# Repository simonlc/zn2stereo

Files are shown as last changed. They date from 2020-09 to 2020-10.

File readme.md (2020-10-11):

# Capcom ZN-2 stereo breakout board

The ZN-2 stereo breakout board is a custom PCB that connects to a ZN-2 audio header and provide line level stereo output. The attenuation circuit is based on the Sanwa VC-J [documented here](http://www.neo-geo.com/forums/showthread.php?172861-A-different-attenuation-circuit).

It's mounted by a single standoff, and is supported by the connector that sits on the stereo header.

- Online BOM: https://octopart.com/bom-tool/YipwlKb2
- Purchase bare PCB online: https://oshpark.com/shared_projects/Dj41HkF0

### Donate: https://paypal.me/zn2stereo

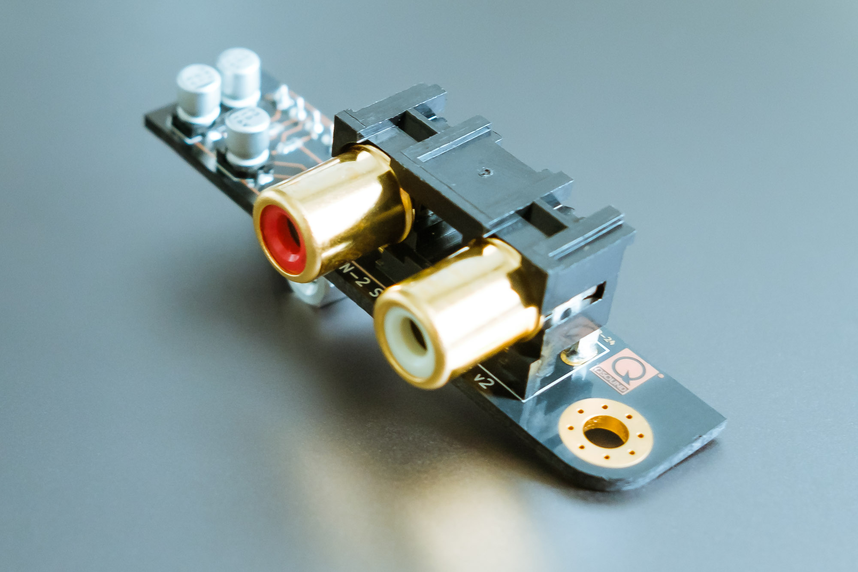
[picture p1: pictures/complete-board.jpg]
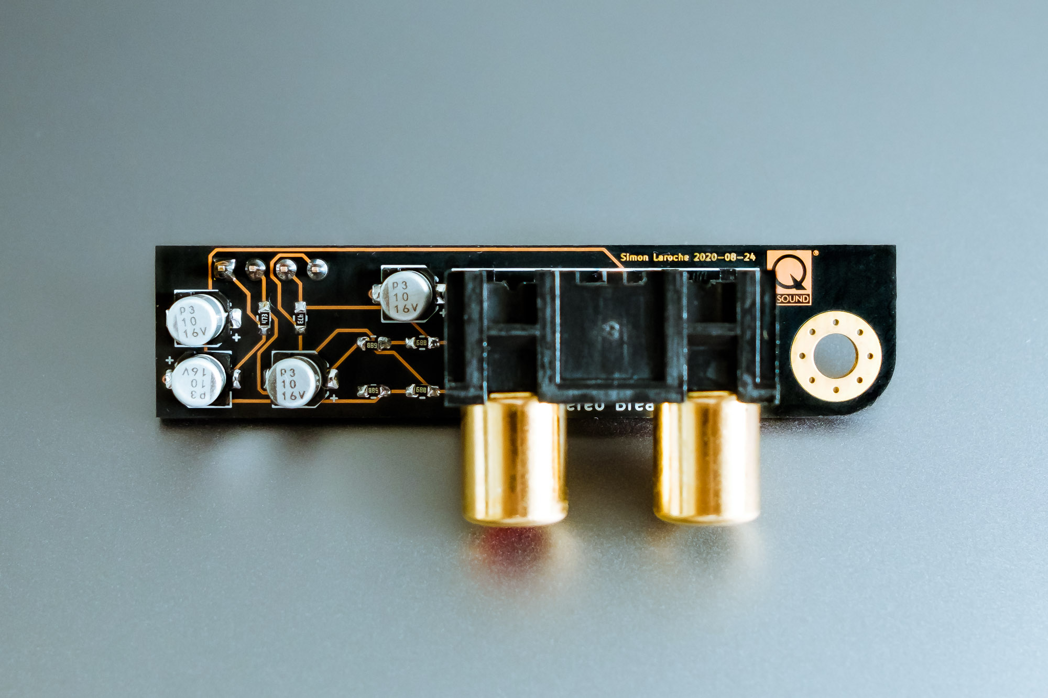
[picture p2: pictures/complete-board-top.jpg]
 

## Assembly

To assemble the board, soldering experience is needed. Parts in the BOM must be acquired, and a custom PCB printed. The PCB can be printed from anywhere, but a link is provided to purchase from OSH Park for convenience. If you have any questions regarding the installation or purchase please create an issue.

## Installation

For ZN-2 games, the stereo/mono switch next to the volume pot must be set to stereo. The game also needs to be set to stereo in the test menu.

The BOM includes M3 standoff and screws. Depending on your PCB standoffs, these might not be the right size, please double check!

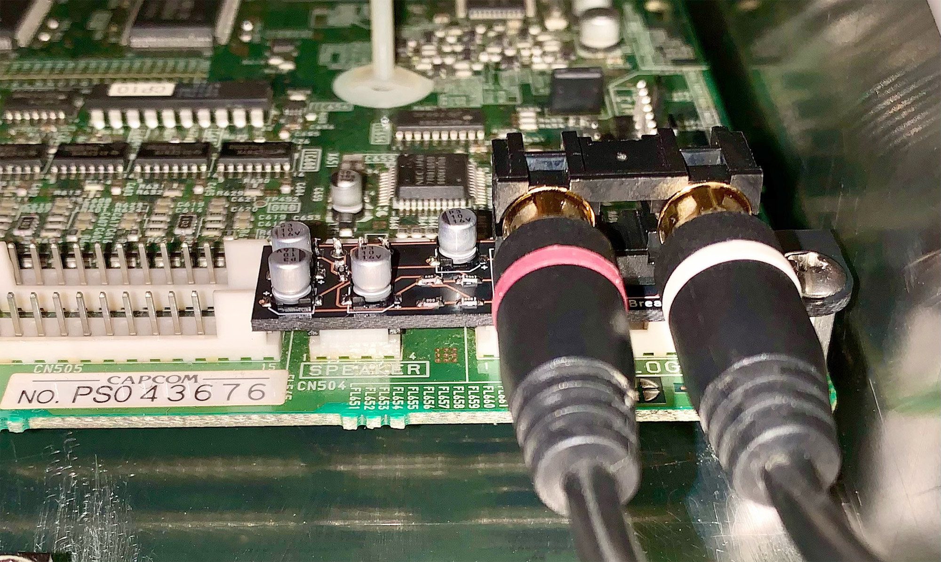
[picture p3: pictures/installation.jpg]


## Compatibility

This board may be compatible with other ZN-2 style hardware.

| Hardware | Compatibility |
| --- | --- |
| Capcom ZN-2 | ✅  Working |
| Capcom ZN-1 | ✅  Working |
| Taito G-Net | ❓  Not tested |
| Tecmo TPS | ❓  Not tested |
| Taito FX-1A System | ❓  Not tested |
| Taito FX-1B System | ❓  Not tested |

## License
Licensed under the TAPR Open Hardware License (www.tapr.org/OHL)

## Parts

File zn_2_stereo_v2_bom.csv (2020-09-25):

Qty | Line Item | Manufacturer | MPN | Octopart URL | Schematic Reference | Internal Part Number | Description | Total Qty (@ Batch Size: 3) | SKU | SKU | SKU | SKU | Packaging | Packaging | Packaging | Packaging | Unit Price (@ Batch Size: 3) | Unit Price (@ Batch Size: 3) | Unit Price (@ Batch Size: 3) | Unit Price (@ Batch Size: 3) | In Stock | In Stock | In Stock | In Stock | MOQ | MOQ | MOQ | MOQ | URL | URL | URL | URL | Distributor [Lowest Price (Overall)] | SKU [Lowest Price (Overall)] | Packaging [Lowest Price (Overall)] | Unit Price (@ Batch Size: 3) [Lowest Price (Overall)] | Line Total [Lowest Price (Overall)] | Batch Total [Lowest Price (Overall)] | In Stock [Lowest Price (Overall)] | MOQ [Lowest Price (Overall)] | URL [Lowest Price (Overall)] | Notes
 |  |  |  |  |  |  |  |  | Digi-Key | Future Electronics | Mouser | RS Components | Digi-Key | Future Electronics | Mouser | RS Components | Digi-Key | Future Electronics | Mouser | RS Components | Digi-Key | Future Electronics | Mouser | RS Components | Digi-Key | Future Electronics | Mouser | RS Components | Digi-Key | Future Electronics | Mouser | RS Components
1 | PJRAN2X1U01AUX | Switchcraft | PJRAN2X1U01AUX | https://octopart.com/pjran2x1u01aux-switchcraft-7628639 |  |  | Stereo RCA jacks | 3 | SC2534-ND |  | 502-PJRAN2X1U01AUX |  | Bulk |  |  |  | 3.2303490999999998 |  | 2.9500295499999996 |  | 290 |  | 2021 |  | 1 |  | 1 |  | https://octopart.com/click/track?ai=8237&sig=036b407&sid=459&ppid=7628639&vpid=410285749&ct=offers |  | https://octopart.com/click/track?ai=8237&sig=053ed9f&sid=2401&ppid=7628639&vpid=84769496&ct=offers |  | Newark | 09N0908 |  | 2.23 | 2.23 | 6.6899999999999995 | 23 | 1 | https://octopart.com/click/track?ai=8237&sig=038ab07&sid=2402&ppid=7628639&vpid=496454911&ct=offers
4 | CR0603-FX-4991ELF | Bourns | CR0603-FX-4991ELF | https://octopart.com/cr0603-fx-4991elf-bourns-2326660 |  |  | 5K resistor | 12 | CR0603-FX-4991ELFCT-ND |  | 652-CR0603FX-4991ELF |  | Cut Tape |  | Tape & Reel |  | 0.020022824999999998 |  | 0.026697099999999998 |  | 87845 |  | 50585 |  | 1 |  | 1 |  | https://octopart.com/click/track?ai=8237&sig=0655f03&sid=459&ppid=2326660&vpid=61158165&ct=offers |  | https://octopart.com/click/track?ai=8237&sig=034b805&sid=2401&ppid=2326660&vpid=37729650&ct=offers |  | Arrow Electronics | CR0603-FX-4991ELF | Cut Tape | 0.013348549999999999 | 0.053394199999999996 | 0.16018259999999998 | 19804 | 1 | https://octopart.com/click/track?ai=8237&sig=035ebea&sid=1106&ppid=2326660&vpid=473159437&ct=offers
4 | UWX1C100MCL1GB | Nichicon | UWX1C100MCL1GB | https://octopart.com/uwx1c100mcl1gb-nichicon-203107 |  |  | Capacitor | 12 | 493-2100-1-ND | 7940968 | 647-UWX1C100MCL1 | 7395548 | Cut Tape | Cut Tape | Tape & Reel |  | 0.21357679999999998 | 0.353736575 | 0.353736575 | 0.19411069810396556 | 179 | 3011 | 25372 | 480 | 1 | 1 | 1 | 10 | https://octopart.com/click/track?ai=8237&sig=0481c12&sid=459&ppid=203107&vpid=1196165&ct=offers | https://octopart.com/click/track?ai=8237&sig=0ecec06&sid=2454&ppid=203107&vpid=19666315&ct=offers | https://octopart.com/click/track?ai=8237&sig=0613dbd&sid=2401&ppid=203107&vpid=39505068&ct=offers | https://octopart.com/click/track?ai=8237&sig=0d7caaa&sid=10022&ppid=203107&vpid=199081830&ct=offers | LCSC | C445047 |  | 0.0642 | 0.2568 | 0.7704 | 1900 | 10 | https://octopart.com/click/track?ai=8237&sig=0725ec1&sid=27971&ppid=203107&vpid=609063197&ct=offers
2 | CRCW060347K0JNEAC | Vishay | CRCW060347K0JNEAC | https://octopart.com/crcw060347k0jneac-vishay-23798439 |  |  | 47K resistor | 6 | 541-4061-1-ND |  | 71-CRCW060347K0JNEAC |  | Cut Tape |  | Tape & Reel |  | 0.1334855 |  | 0.1334855 |  | 98410 |  | 28688 |  | 1 |  | 1 |  | https://octopart.com/click/track?ai=8237&sig=00cb439&sid=459&ppid=23798439&vpid=454353578&ct=offers |  | https://octopart.com/click/track?ai=8237&sig=05cf147&sid=2401&ppid=23798439&vpid=458953569&ct=offers |  | Arrow.cn | CRCW060347K0JNEAC#VISHAY |  | 0.08593176710061944 | 0.17186353420123887 | 0.5155906026037166 | 7530 | 1 | https://octopart.com/click/track?ai=8237&sig=0a4e952&sid=28928&ppid=23798439&vpid=617453892&ct=offers
1 | PPPC041LFBN-RC | Sullins | PPPC041LFBN-RC | https://octopart.com/pppc041lfbn-rc-sullins-271053 |  |  | 4 pin connector | 3 | S7037-ND | 6009019 |  |  | Tray | Tray |  |  | 0.6273818499999999 | 0.3804336749999999 |  |  | 30804 | 5313 |  |  | 1 | 1 |  |  | https://octopart.com/click/track?c=1&ai=8237&sig=038629e&sid=459&ppid=271053&vpid=1385044&ct=offers | https://octopart.com/click/track?ai=8237&sig=075b0fd&sid=2454&ppid=271053&vpid=110050916&ct=offers |  |  | Future Electronics | 6009019 | Tray | 0.3804336749999999 | 0.3804336749999999 | 1.1413010249999997 | 5313 | 1 | https://octopart.com/click/track?ai=8237&sig=075b0fd&sid=2454&ppid=271053&vpid=110050916&ct=offers
1 | 24337 | Keystone | 24337 | https://octopart.com/24337-keystone-7139829 |  |  | 1 cm M3 Standoff | 3 | 36-24337-ND | 1054718 | 534-24337 |  | Bulk | Bulk | Bulk |  | 0.6273818499999999 |  | 0.60068475 |  | 5739 | 8 | 3426 |  | 1 | 100 | 1 |  | https://octopart.com/click/track?ai=8237&sig=064ec3c&sid=459&ppid=7139829&vpid=212424319&ct=offers | https://octopart.com/click/track?ai=8237&sig=05daba1&sid=2454&ppid=7139829&vpid=416853497&ct=offers | https://octopart.com/click/track?ai=8237&sig=04f8fe6&sid=2401&ppid=7139829&vpid=37671153&ct=offers |  | Carlton-Bates | 78382495417 |  | 0.5472905499999999 | 0.5472905499999999 | 1.6418716499999997 | 0 | 1 | https://octopart.com/click/track?c=1&ai=8237&sig=027bb87&sid=18369&ppid=7139829&vpid=521657115&ct=offers
1 | MPMS 003 0005 PH | Building Fasteners | MPMS 003 0005 PH | https://octopart.com/mpms+003+0005+ph-building+fasteners-374100 |  |  | M3 screw | 3 | H742-ND |  |  |  | Bulk |  |  |  |  |  |  |  | 40100 |  |  |  | 100 |  |  |  | https://octopart.com/click/track?c=1&ai=8237&sig=0800b8d&sid=459&ppid=374100&vpid=1717444&ct=offers |  |  |  | Digi-Key | H742-ND | Bulk |  |  |  | 40100 | 100 | https://octopart.com/click/track?c=1&ai=8237&sig=0800b8d&sid=459&ppid=374100&vpid=1717444&ct=offers

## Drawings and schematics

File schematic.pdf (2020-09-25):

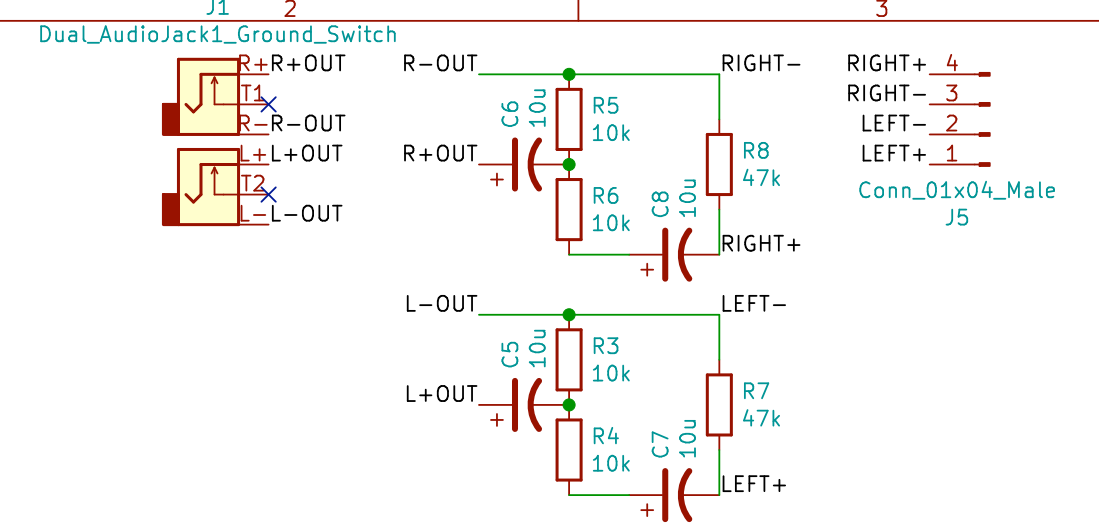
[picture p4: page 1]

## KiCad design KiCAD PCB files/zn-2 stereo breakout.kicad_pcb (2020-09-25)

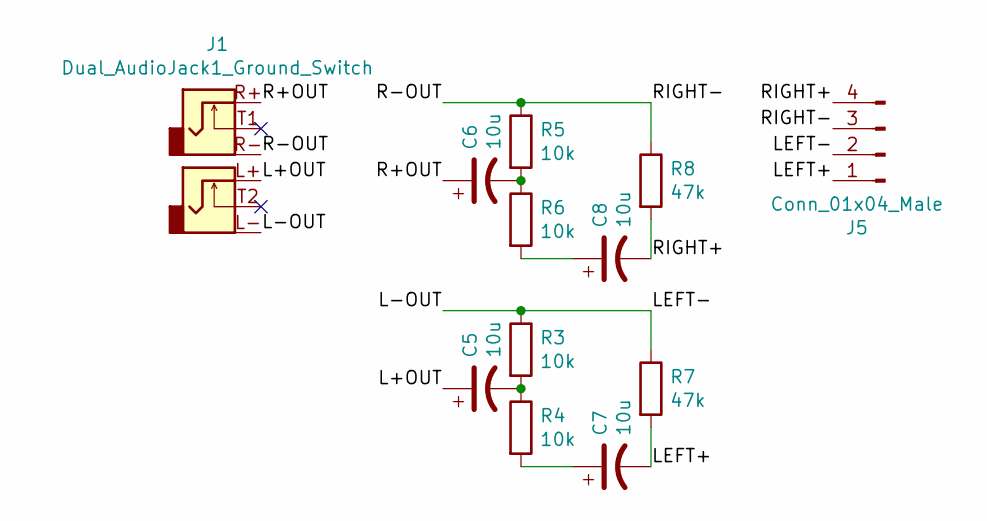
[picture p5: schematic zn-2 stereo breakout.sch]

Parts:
C5, C6, C7, C8: 10u; CP_Elec_4x5.8
J1: Dual_AudioJack1_Ground_Switch; Switchcraft PJRAN2X1U01AUX
J5: Conn_01x04_Male; PinSocket_1x04_P2.54mm_Vertical
R3, R4, R5, R6: 10k; R_0603_1608Metric_Pad1.05x0.95mm_HandSolder
R7, R8: 47k; R_0603_1608Metric_Pad1.05x0.95mm_HandSolder

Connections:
/L+OUT: C5.1, J1.L+
/L-OUT: J1.L-, J5.2, R3.1, R7.1
/LEFT+: C7.2, J5.1, R7.2
/R+OUT: C6.1, J1.R+
/R-OUT: J1.R-, J5.3, R5.1, R8.1
/RIGHT+: C8.2, J5.4, R8.2
unnamed: C5.2, R3.2, R4.1
unnamed: C6.2, R5.2, R6.1
unnamed: C7.1, R4.2
unnamed: C8.1, R6.2

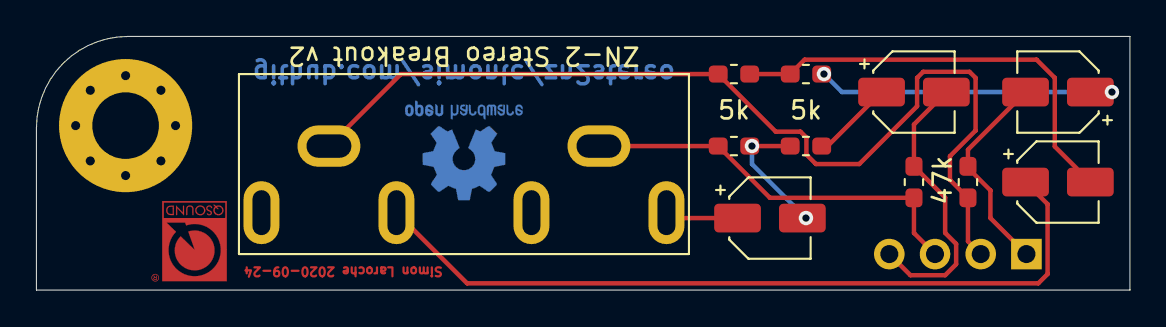
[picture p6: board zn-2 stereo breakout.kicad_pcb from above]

Board: 2 copper layers, 60.8 x 14.1 mm, 12 parts (1 on the bottom side), 10 nets.

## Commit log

2020-09-25 Add section on assembly
2020-09-25 Move bom file
    [zn_2_stereo_v2_bom.csv]
2020-09-25 Update BOM and add section in readme about standoffs
    [zn_2_stereo_v2_bom.csv]
